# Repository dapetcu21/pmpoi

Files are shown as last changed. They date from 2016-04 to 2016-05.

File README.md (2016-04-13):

# PM Poi

> Visual Poi hardware project.

## Definitions

[Poi - performance art, Wikipedia page](https://en.wikipedia.org/wiki/Poi_(performance_art)#Glow_poi.2Fglowstringing)

It looks like this:

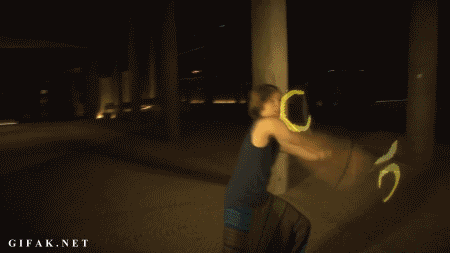
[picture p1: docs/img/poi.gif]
Demo


## About this project

This is my project for the MCU programming class from University.

## Hardware

Since this is a project for Uni, we had to use the provided ATMEGA324PA development [board](./hardware/pm2016.brd).

On top of it, I created an extension [board](./hardware/pmpoi.sch) with a shield-like form factor.

The main stars of the extension board are:

  * 8 RGB LEDs connected to the entirety of PORTB, PORTD and PORTA through a set of transitor array ICs. I could have used some PWM driver IC, but then where's all the fun? (To be read as: I didn't want to wait for the parts, so I just used what I could readily find at my local vendor.)

  * an MPU6050 gyro (on a GY-521 breakout board).

  * 3 buttons for good measure.

  * 3 AAA batteries to keep the board running.

Since this will spin freely in the air, I needed to make it sturdy, so I used screw mount dividers and no ribbon cables for the build.

Of course, most poi tehnique requires two poi, so I had to make two.

Attach this to a set of poi leashes and we're ready to dance.

### Caveats

Since I configured my bootloader to start when PD7 is pressed (sunk to GND) and I also connected PD7 to the input of the transistor array (which also pulled to GND, probably in a more stronger fashion than the 20K internal pull-up on PD7 protects against), I had to add a stronger pull-up resistor on that pin (3.3K).

Of course, since I also had to use PD2 and PD3 for the LEDs, plugging this into a computer won't do anything. But then if you want to program it, sometimes a reset is not be enough for your computer to pick it up. You might have to unplug the cable, wait a few seconds and plug it again. This happens because your computer's USB controller remembers that a non-compliant USB device was plugged into that port and decides to ignore it, even if you decide to send valid USB traffic at some point.

## Software

For the bootloader, I used [USBaspLoader](https://github.com/baerwolf/USBaspLoader) since it works via V-USB and plays nice with avrdude.

As a development environment, I just wrote a `Makefile` and a `.clang_complete` file to get autocomplete to work and built the whole thing in Atom.

### LED PWM

Since I have to drive 8 RGB LEDs (24 independent channels) in software PWM operation, I decided to use a novel approach:

Since PWM has to be fast, we have to keep our timer's ISR small.

I decided to use all the pins from 3 ports because it's easy to change them all at the same time. That's why, every time I would need to change the color of the LEDs, I would pre-calculate a render buffer with `B[i]`, the state of the each of the 3 ports at the time `i`. We can make `i` sweep from `0` to `15` and then loop around as the timer ticks.

For example, let's say I want to keep one of the LEDs at 25% brightness. I would first figure out what's the corresponding port and bit for the LED, then mark it as `1` in `B[0]`, `B[1]`, `B[2]`, `B[3]` and as `0` in `B[4- 15]`. This way, as the timer sweeps the render buffer, the LED will be lit 4 times out of 16.

Because modifying the render buffer during rendering might cause unexpected flickers, I decided to go with a double buffered approach. Every time I need to update the color of the LEDs, I fill in an off-screen render buffer, then mark it as ready for display. The ISR would then swap it with its current render buffer at the end of a `0 - 16` cycle (frame).

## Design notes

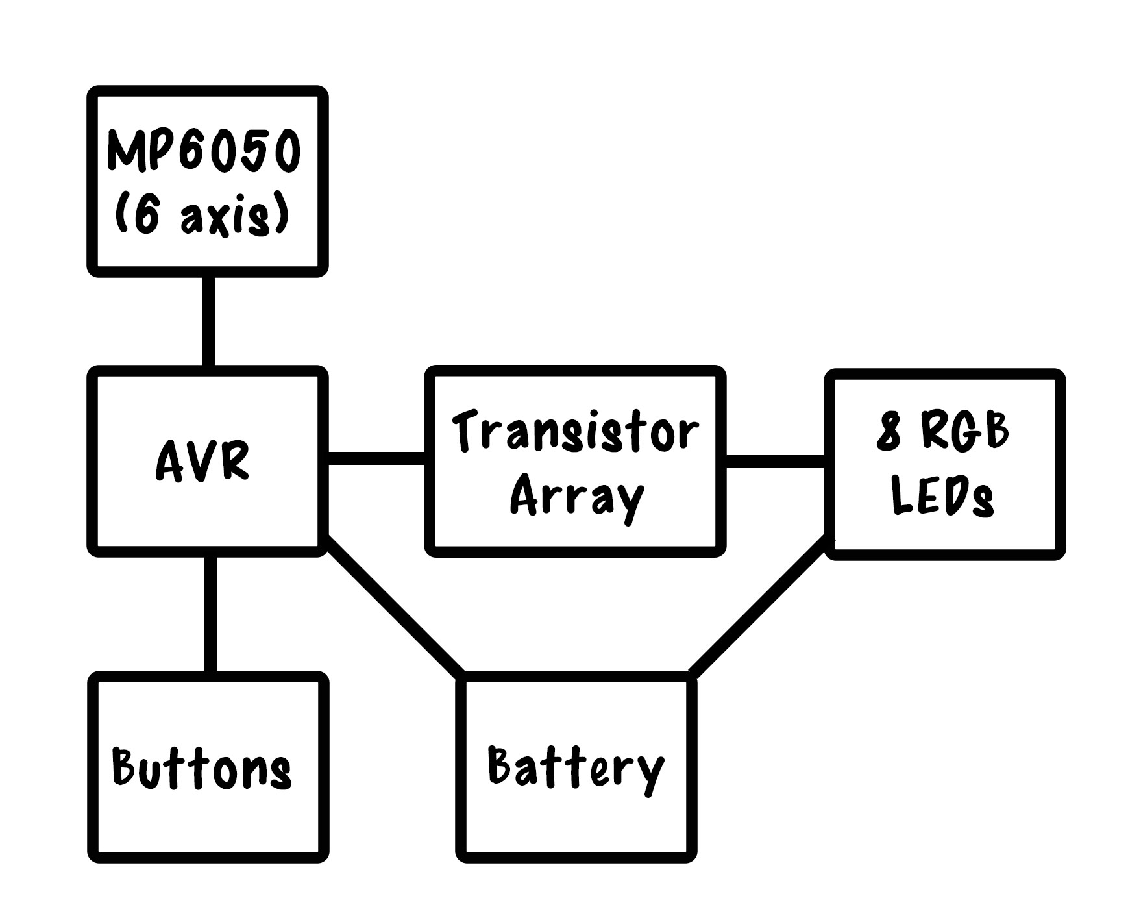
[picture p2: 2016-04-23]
docs/img/diagram.jpg

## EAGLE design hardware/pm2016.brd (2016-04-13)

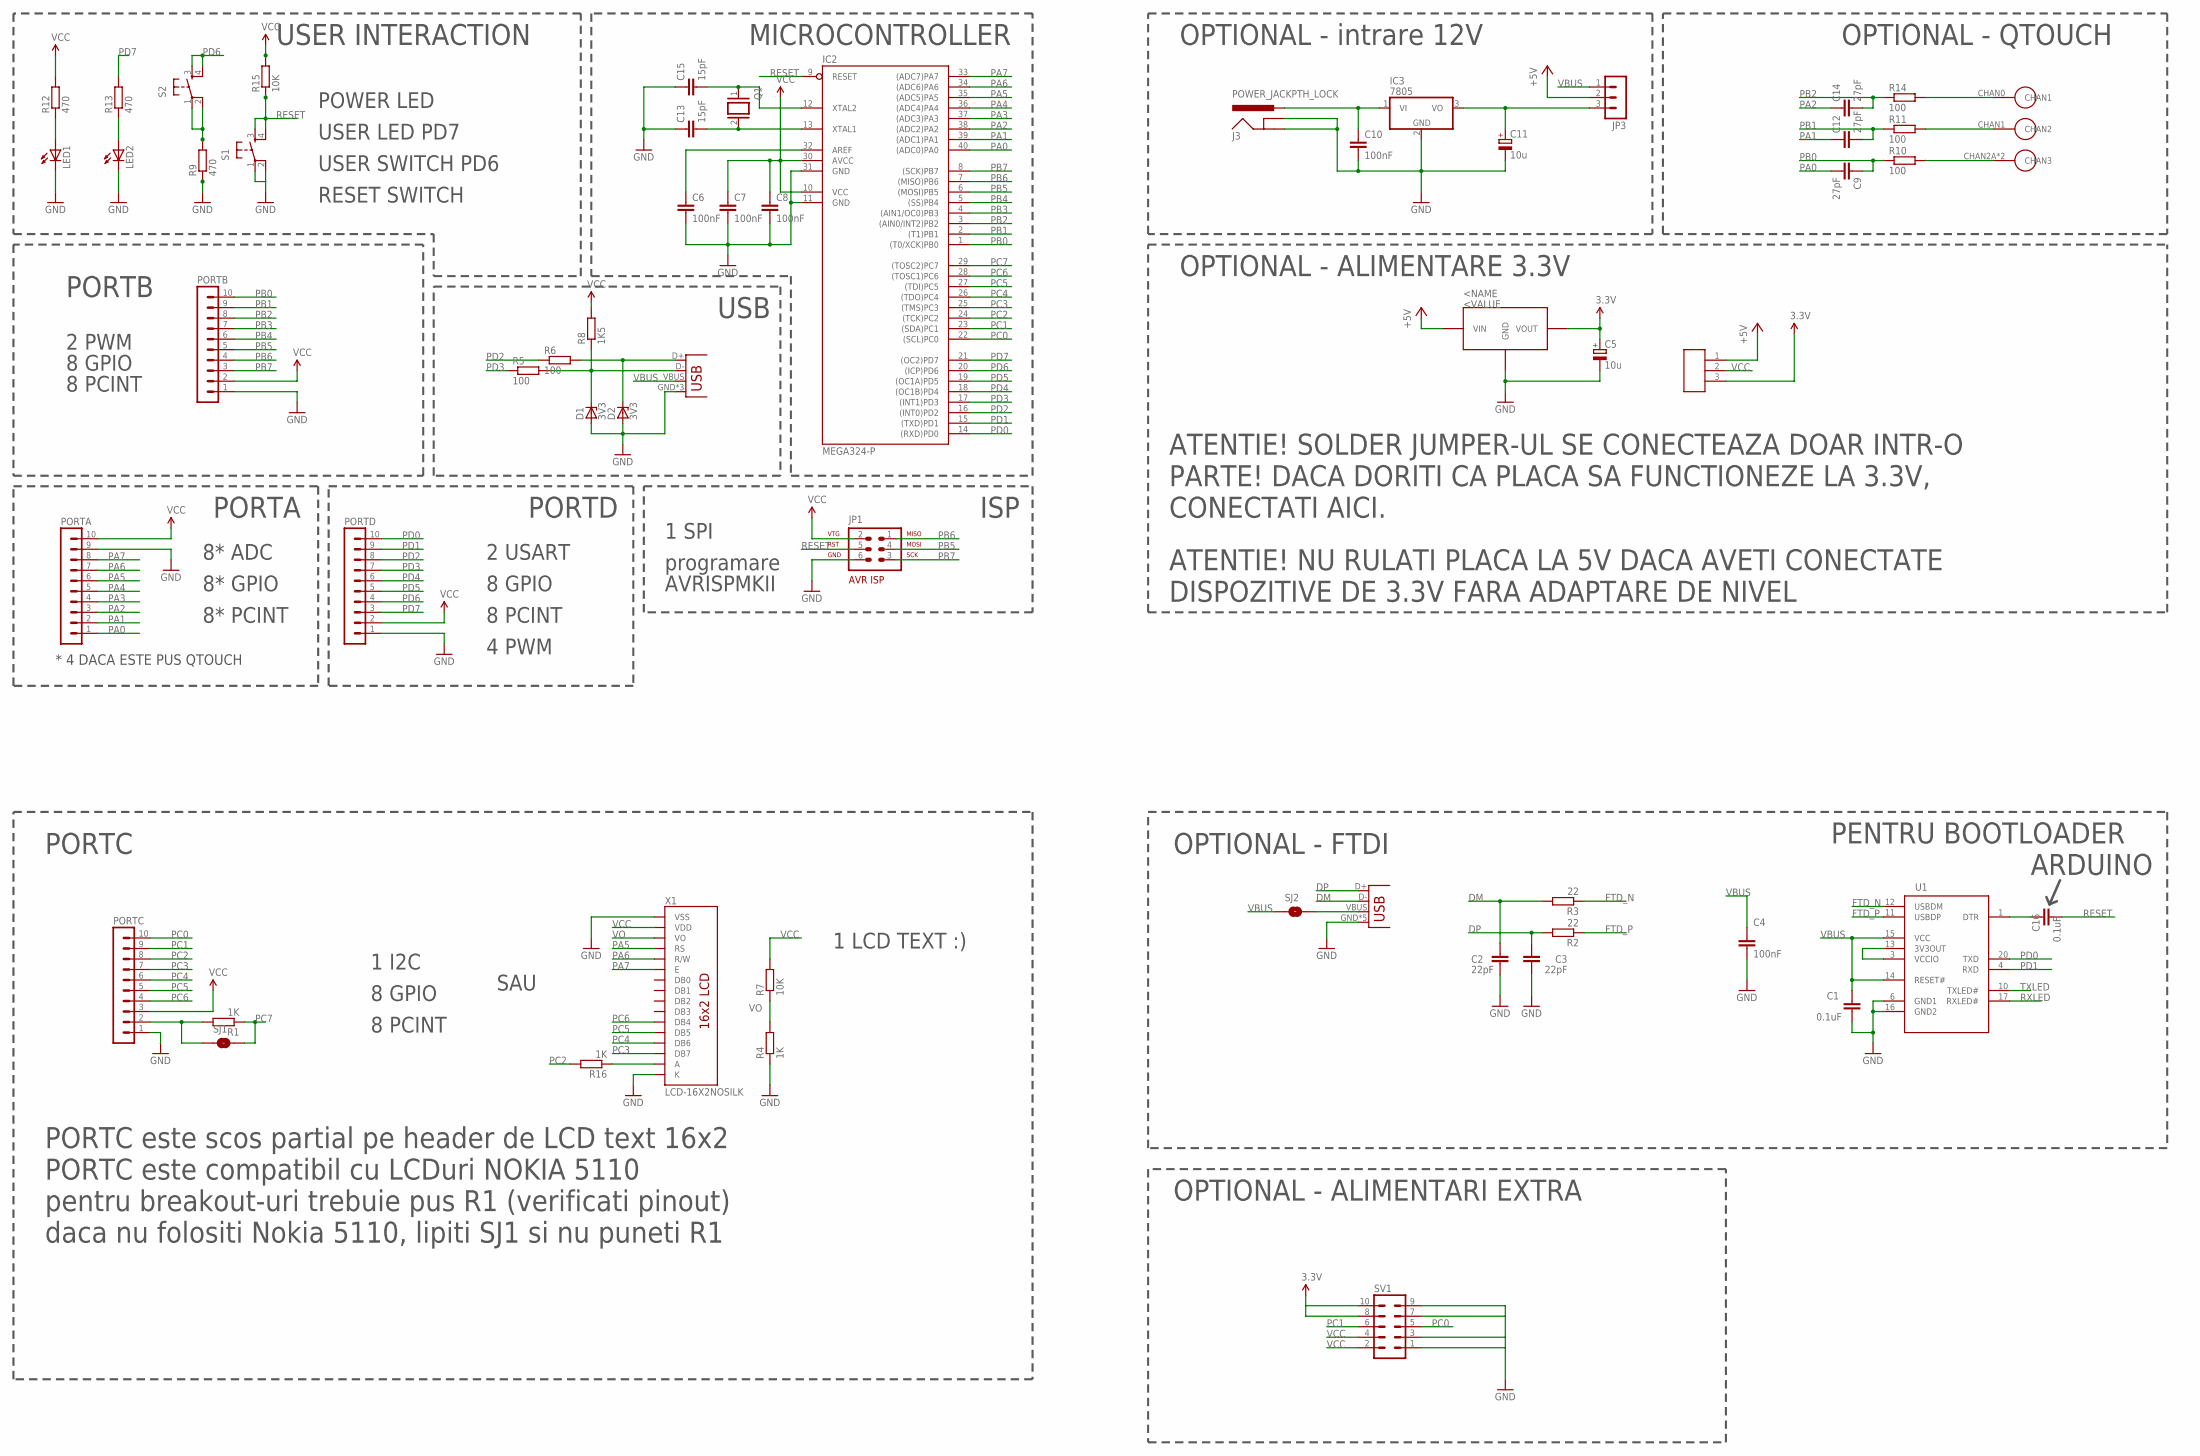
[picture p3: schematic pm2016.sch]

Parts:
C1, C16: 0.1uF; C0603
C2, C3: 22pF; C0603
C4: 100nF; C0603
C5, C11: 10u; E2,5-5
C6, C7, C8: 100nF; C025-025X050
C9, C12, C14: 27pF; C1206
C10: 100nF; C025-025X050@1
C13, C15: 15pF; C025-025X050
D1, D2: 3V3; DO34Z7
IC1: LE33; TO92
IC2: MEGA324-P; DIL40
IC3: 7805; TO22H_NOHOLE
J1: USB; ZX62D-B-5PA8
J2: USBPTH; USB-B-PTH
J3: POWER_JACKPTH_LOCK; POWER_JACK_PTH_LOCK
JP1: AVR-ISP-6
JP2: SJUMPER; SJUMPER_PACK
JP3: MA03-1
LED1, LED2: LED5MM
PORTA: MA10-1
PORTB: MA10-1
PORTC: MA10-1
PORTD: MA10-1
Q1: XTAL/S; QS
R1, R4, R16: 1K; 0204/7
R2, R3: 22; R0603
R5, R6: 100; 0204/7
R7, R15: 10K; 0204/7
R8: 1K5; 0204/7
R9, R12, R13: 470; 0204/7
R10, R11, R14: 100; M1206
S1, S2: TAC_SWITCHPTH; TACTILE-PTH
SJ1, SJ2: SOLDERJUMPERNC; SJ-NC
SV1: MA05-2
U1: FT231XS; SSOP20
U$1: QT_SLIDER
X1: LCD-16X2NOSILK; LCD-16X2_NOSILK

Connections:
3.3V: C5.+, IC1.1 (VOUT), JP2.3, SV1.8, SV1.10
+5V: IC1.3 (VIN), JP2.1, JP3.2
DM: C2.2, J1.D-, R3.2
DP: C3.2, J1.D+, R2.2
FTD_N: R3.1, U1.12 (USBDM)
FTD_P: R2.1, U1.11 (USBDP)
GND: C1.2, C2.1, C3.1, C4.2, C5.-, C6.2, C7.2, C8.2, C10.2, C11.-, C13.1, C15.1, D1.A, D2.A, IC1.2 (GND), IC2.11 (GND), IC2.31 (GND), IC3.2 (GND), J1.GND, J1.P$8 (GND), J1.P$9 (GND), J1.P$10 (GND), J1.P$11 (GND), J2.GND, J2.P$1 (GND), J2.P$2 (GND), J3.GND, J3.GNDBREAK, JP1.6, LED1.K (C), LED2.K (C), PORTA.9, PORTB.1, PORTC.1, PORTD.1, R4.1, R9.1, S1.1, S1.2, SV1.1, SV1.3, SV1.7, SV1.9, U1.6 (GND1), U1.16 (GND2), X1.1 (VSS), X1.16 (K)
unnamed: LED2.A, R13.1
unnamed: LED1.A, R12.1
unnamed: PORTC.2, R1.2, SJ1.1
unnamed: J1.VBUS, SJ2.2
unnamed: R14.2, U$1.CHAN0 (CHAN1)
unnamed: R11.2, U$1.CHAN1 (CHAN2)
unnamed: R10.2, U$1.CHAN2A (CHAN3), U$1.CHAN2B (CHAN3)
unnamed: R16.1, X1.15 (A)
unnamed: C16.1, U1.1 (DTR)
unnamed: U1.3 (VCCIO), U1.13 (3V3OUT)
unnamed: D2.C, J2.D+, R6.2
unnamed: D1.C, J2.D-, R5.2, R8.1
unnamed: C10.1, IC3.1 (VI), J3.PWR
unnamed: R9.2, S2.1, S2.2
unnamed: C11.+, IC3.3 (VO), JP3.3
unnamed: C6.1, IC2.32 (AREF)
unnamed: C13.2, IC2.13 (XTAL1), Q1.2
unnamed: C15.2, IC2.12 (XTAL2), Q1.1
PA0: C9.2, IC2.40 ((ADC0)PA0), PORTA.1
PA1: C12.1, IC2.39 ((ADC1)PA1), PORTA.2
PA2: C14.1, IC2.38 ((ADC2)PA2), PORTA.3
PA3: IC2.37 ((ADC3)PA3), PORTA.4
PA4: IC2.36 ((ADC4)PA4), PORTA.5
PA5: IC2.35 ((ADC5)PA5), PORTA.6, X1.4 (RS)
PA6: IC2.34 ((ADC6)PA6), PORTA.7, X1.5 (R/W)
PA7: IC2.33 ((ADC7)PA7), PORTA.8, X1.6 (E)
PB0: C9.1, IC2.1 ((T0/XCK)PB0), PORTB.10, R10.1
PB1: C12.2, IC2.2 ((T1)PB1), PORTB.9, R11.1
PB2: C14.2, IC2.3 ((AIN0/INT2)PB2), PORTB.8, R14.1
PB3: IC2.4 ((AIN1/OC0)PB3), PORTB.7
PB4: IC2.5 ((SS)PB4), PORTB.6
PB5: IC2.6 ((MOSI)PB5), JP1.4, PORTB.5
PB6: IC2.7 ((MISO)PB6), JP1.1, PORTB.4
PB7: IC2.8 ((SCK)PB7), JP1.3, PORTB.3
PC0: IC2.22 ((SCL)PC0), PORTC.10, SV1.5
PC1: IC2.23 ((SDA)PC1), PORTC.9, SV1.6
PC2: IC2.24 ((TCK)PC2), PORTC.8, R16.2
PC3: IC2.25 ((TMS)PC3), PORTC.7, X1.14 (DB7)
PC4: IC2.26 ((TDO)PC4), PORTC.6, X1.13 (DB6)
PC5: IC2.27 ((TDI)PC5), PORTC.5, X1.12 (DB5)
PC6: IC2.28 ((TOSC1)PC6), PORTC.4, X1.11 (DB4)
PC7: IC2.29 ((TOSC2)PC7), R1.1, SJ1.2
PD0: IC2.14 ((RXD)PD0), PORTD.10, U1.20 (TXD)
PD1: IC2.15 ((TXD)PD1), PORTD.9, U1.4 (RXD)
PD2: IC2.16 ((INT0)PD2), PORTD.8, R6.1
PD3: IC2.17 ((INT1)PD3), PORTD.7, R5.1
PD4: IC2.18 ((OC1B)PD4), PORTD.6
PD5: IC2.19 ((OC1A)PD5), PORTD.5
PD6: IC2.20 ((ICP)PD6), PORTD.4, S2.3, S2.4
PD7: IC2.21 ((OC2)PD7), PORTD.3, R13.2
RESET: C16.2, IC2.9 (RESET), JP1.5, R15.1, S1.3, S1.4
RXLED: U1.17 (RXLED#)
TXLED: U1.10 (TXLED#)
VBUS: C1.1, C4.1, J2.VBUS, JP3.1, SJ2.1, U1.14 (RESET#), U1.15 (VCC)
VCC: C7.1, C8.1, IC2.10 (VCC), IC2.30 (AVCC), JP1.2, JP2.2, PORTA.10, PORTB.2, PORTC.3, PORTD.2, R7.2, R8.2, R12.2, R15.2, SV1.2, SV1.4, X1.2 (VDD)
VO: R4.2, R7.1, X1.3 (VO)

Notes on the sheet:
8* ADC
8* GPIO
8* PCINT
* 4 DACA ESTE PUS QTOUCH
1 I2C
8 GPIO
8 PCINT
2 USART
4 PWM
1 SPI
programare
AVRISPMKII
PORTA
PORTC
PORTD
USB
ISP
POWER LED
USER LED PD7
USER SWITCH PD6
RESET SWITCH
USER INTERACTION
MICROCONTROLLER
OPTIONAL - intrare 12V
OPTIONAL - QTOUCH
OPTIONAL - ALIMENTARE 3.3V
ATENTIE! SOLDER JUMPER-UL SE CONECTEAZA DOAR INTR-O
PARTE! DACA DORITI CA PLACA SA FUNCTIONEZE LA 3.3V,
CONECTATI AICI.
ATENTIE! NU RULATI PLACA LA 5V DACA AVETI CONECTATE
DISPOZITIVE DE 3.3V FARA ADAPTARE DE NIVEL
PORTB
2 PWM
1 LCD TEXT :)
SAU
OPTIONAL - FTDI
PORTC este compatibil cu LCDuri NOKIA 5110
pentru breakout-uri trebuie pus R1 (verificati pinout)
daca nu folositi Nokia 5110, lipiti SJ1 si nu puneti R1
PORTC este scos partial pe header de LCD text 16x2

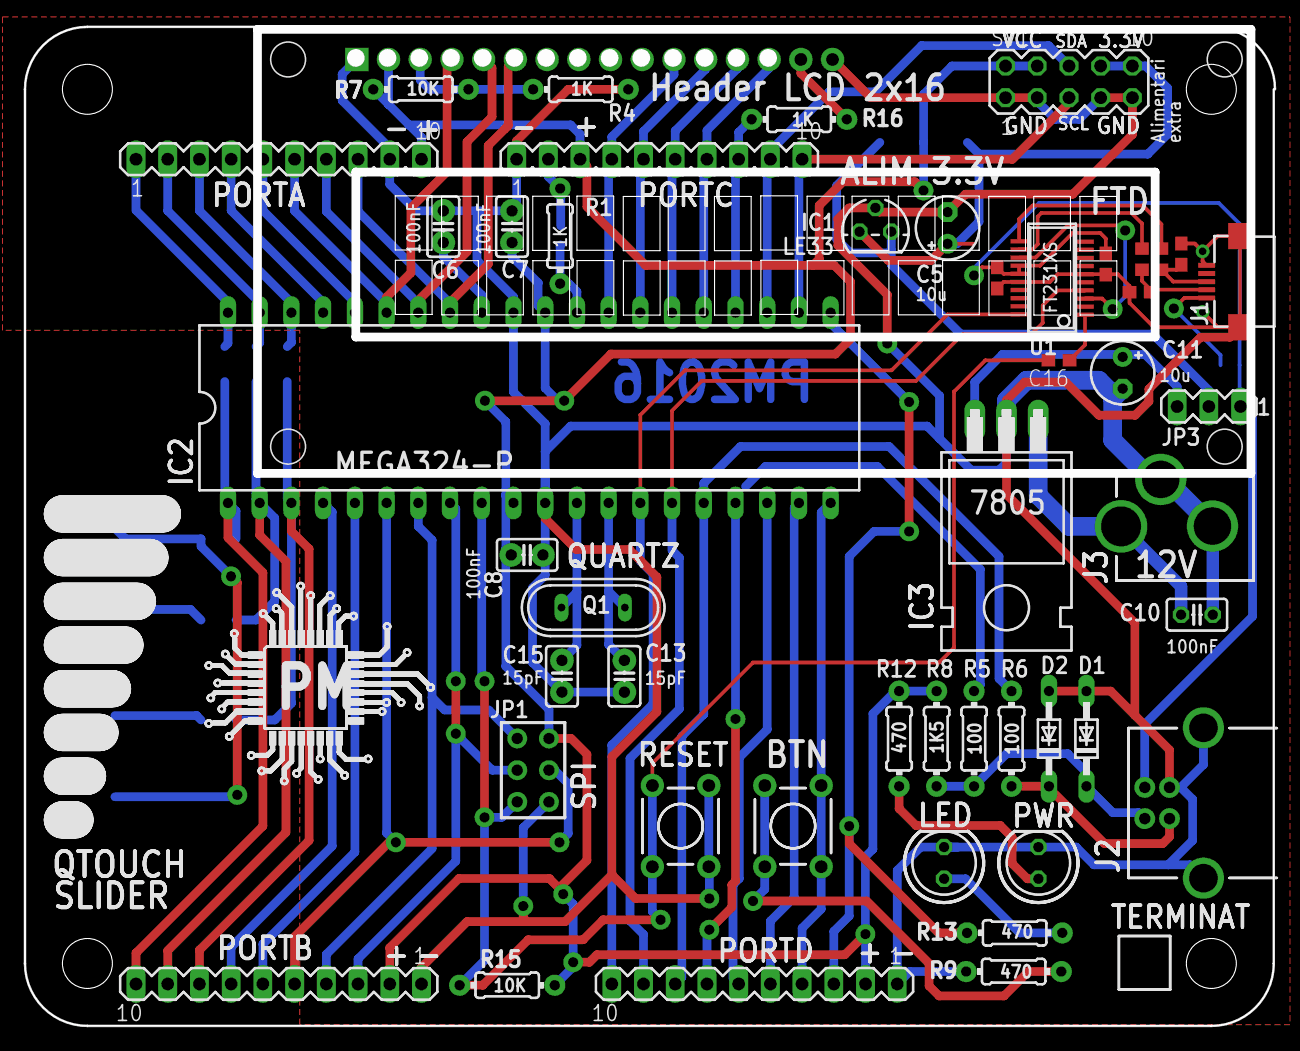
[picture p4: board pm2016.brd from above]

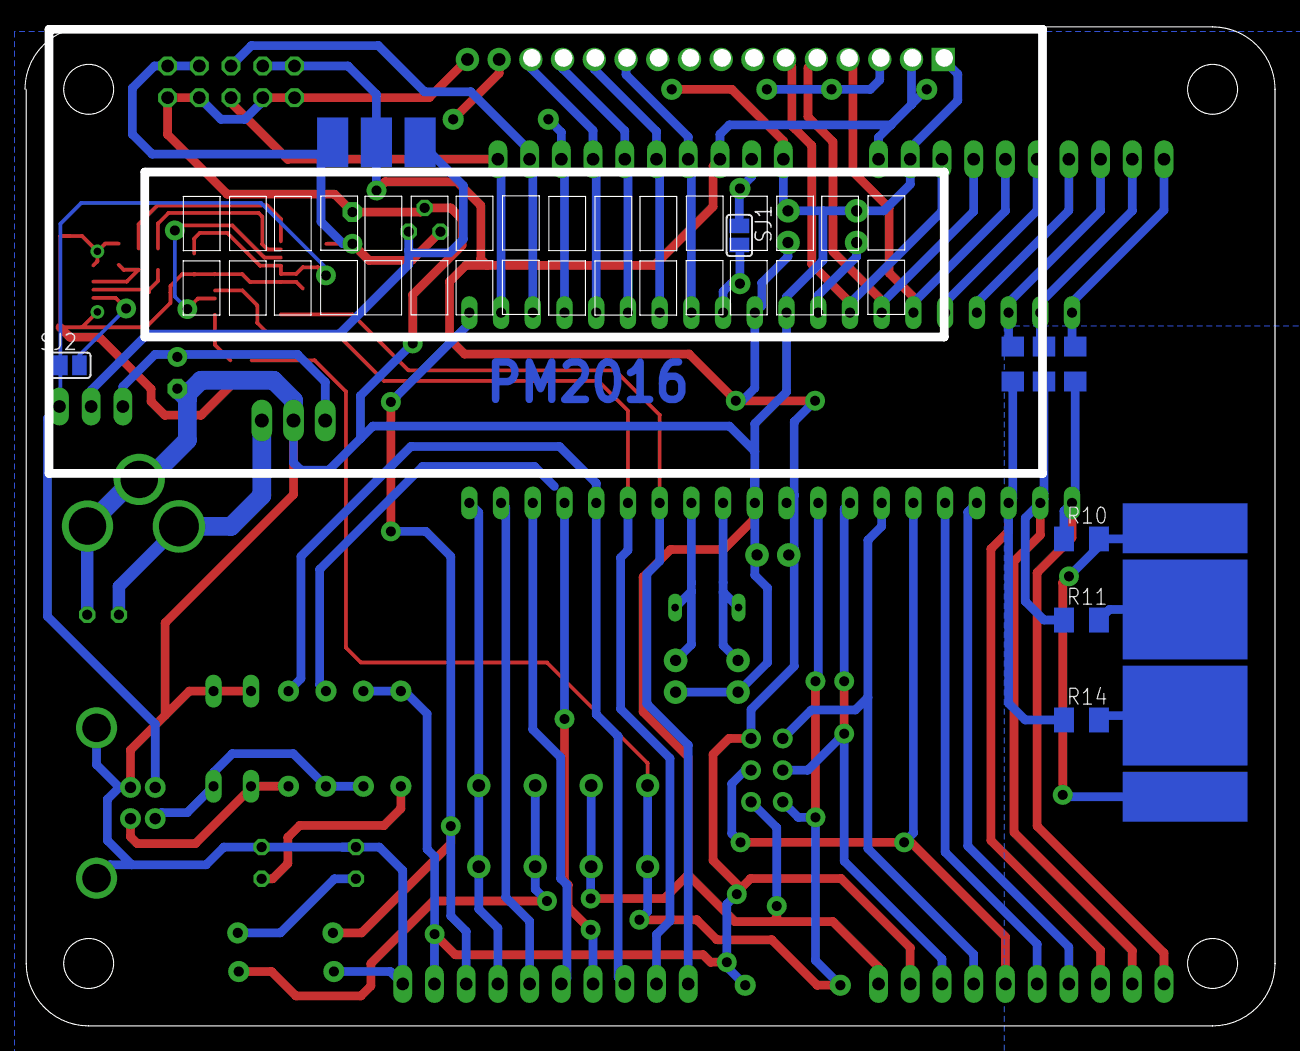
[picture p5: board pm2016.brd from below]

Board: 2 copper layers, 100.1 x 80.0 mm, 58 parts (10 on the bottom side), 61 nets.

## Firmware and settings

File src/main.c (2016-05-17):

#include <avr/io.h>
#include <avr/interrupt.h>
#include <util/delay.h>
#include <mpu6050.h>
#include <i2cmaster.h>
#include <stdlib.h>

#include "pwm.h"
#include "button.h"
#include "time.h"
#include "pattern.h"
#include "eeprom.h"

void buttonOnPress(uint8_t button) {
    switch (button) {
        case BUTTON_LEFT:
            patternMenuDown();
            break;
        case BUTTON_RIGHT:
            patternMenuUp();
            break;
        case BUTTON_A:
            break;
    }
}

void buttonOnRelease(uint8_t button) {
    switch (button) {
        #if MPU6050_GETATTITUDE == 2
            case BUTTON_GYRO_INT:
            if (mpu6050_mpuInterruptEnabled) {
                mpu6050_mpuInterrupt = 1;
            }
            break;
        #endif
    }
}

void setup() {
    // Enable interrupts
    sei();

    // Init button interrupts
    buttonInit();

    // Init time counter
    timeInit();

    // Init the EEPROM
    eepromInit();

    // Init gyro
    i2c_init();
    PORTC &= ~3; // Disable the AVR's I2C pullups since the pullups on the GY-521 are too small
    mpu6050_init();

    // Init PWM
    pwmInit();
    pwmEnable();
}

int main() {
    setup();

    PatternState state;
    state.angularVelocity = 0.0;
    state.deltaAngle = 0.0;
    state.deltaTime = 0;
    state.firstRender = 1;
    state.slowSpinning = 1;

    uint16_t lastTime = timeSinceBoot;
    uint16_t lastFastTime = lastTime - PATTERN_SLOW_DURATION;

    while (1) {
        // Wait for new time step
        while (timeSinceBoot == lastTime) {};

        uint16_t time = timeSinceBoot;
        state.deltaTime = time - lastTime;
        lastTime = time;

        // Read angular velocity from the gyro.
        // Ignore Z axis, as poi can spin around the leash
        int16_t d = 0;
        int16_t gx = 0;
        int16_t gz = 0;
        mpu6050_getRawData(&d, &d, &d, &gx, &d, &gz);
        double gdx = gx * (1.0 / MPU6050_GGAIN);
        double gdz = gz * (1.0 / MPU6050_GGAIN);
        state.angularVelocity = sqrt(gdx * gdx + gdz * gdz);

        // Integrate angular velocity over time
        state.deltaAngle = state.angularVelocity * 0.001 * state.deltaTime;

        // Delay slow spinning state
        if (state.angularVelocity >= PATTERN_SLOW_TRESHOLD) {
            lastFastTime = time;
        }
        state.slowSpinning = (time - lastFastTime >= PATTERN_SLOW_DURATION);

        // Render the pattern
        patternRenderMenu(&state, NULL);

        state.firstRender = 0;
    }

    return 0;
}

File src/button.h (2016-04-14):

#pragma once

#include <avr/io.h>
#include <avr/interrupt.h>
#include <stdint.h>

#define BUTTON_GYRO_INT PC2
#define BUTTON_A PC3
#define BUTTON_RIGHT PC4
#define BUTTON_LEFT PC5

#define BUTTON_MIN PC2
#define BUTTON_MAX PC5

#define BUTTON_HYST_MIN PC3
#define BUTTON_HYST_MAX PC5

#define BUTTON_MASK ((1 << BUTTON_GYRO_INT) | (1 << BUTTON_A) | (1 << BUTTON_LEFT) | (1 << BUTTON_RIGHT))
#define BUTTON_HYSTERESIS_MASK ((1 << BUTTON_A) | (1 << BUTTON_LEFT) | (1 << BUTTON_RIGHT))

#define BUTTON_DDR DDRC
#define BUTTON_PORT PORTC
#define BUTTON_PIN PINC
#define BUTTON_PCICR_BIT PCIE2
#define BUTTON_PCMSK PCMSK2
#define BUTTON_VECT PCINT2_vect

void buttonInit();
void buttonCheckChange();
void buttonOnPress(uint8_t button);
void buttonOnRelease(uint8_t button);

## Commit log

2016-04-13 Working solid color PWM
    [pmpoi.sch]
2016-04-13 Add detailed README
    [pm2016.brd, pm2016.sch]
2016-04-14 Add button interrupts with hysterisis and time counter
2016-04-14 Implement gyro interrupt
2016-04-23 Update schematic with PD7 pull-up
    [pmpoi.sch]

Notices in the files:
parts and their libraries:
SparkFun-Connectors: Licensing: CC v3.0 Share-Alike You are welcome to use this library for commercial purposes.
